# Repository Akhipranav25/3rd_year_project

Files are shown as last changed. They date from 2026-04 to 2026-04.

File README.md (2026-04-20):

# 3rd_year_project
Autonomous docking system for spacecraft
<br>
This repository contains all CAD and code files for the project.
<br>
<br>
The C++ code (arduino_robot_control_code_9.4.ino) is to be run on an Arduino microcontroller and the Python code (distance+pose+estimation+Arduino_v6.4.py) is intended to be run on a Raspberry Pi (recommended Raspberry Pi 4 Model B). The Arduino needs to be connected to the Raspberry Pi via USB for the programs to work. The Arduino program can work using inputs typed in the serial monitor on the Arduino IDE, but the Python program will not run if the Arduino is not connected. The Arduino does not have to have the corresponding program loaded, but there will likely be input buffer overflows if a different program (or no program) is used.
<br>
<br>
The STL files can be directly imported to a slicing software and 3D printed, while the STEP files can be imported into a 3D modelling software and edited. The PT-GD401.step file is the original scissor lift design from the source (GrabCAD [https://grabcad.com/library/stepper-motorized-labjack-pt-gd401-and-pt-gd402-1]) and can be edited or just used as a guide for how to connect the parts. Note that some parts, particularly the top and bottom covers are not critical and the design will function without them.

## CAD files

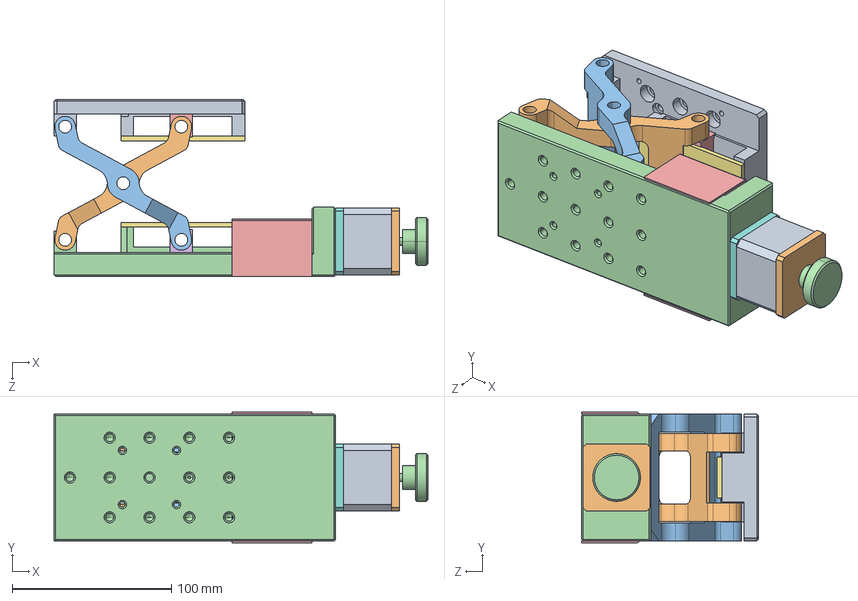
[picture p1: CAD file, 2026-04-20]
PT-GD401.STEP
235.0 x 82.0 x 111.1 mm
ZS10-60怢醱
囀盓殤
俋盓殤
ZS10-60菁啣
賑輸
螺母滑块
絳寢 x 2
YK42萇儂
护罩-60电动

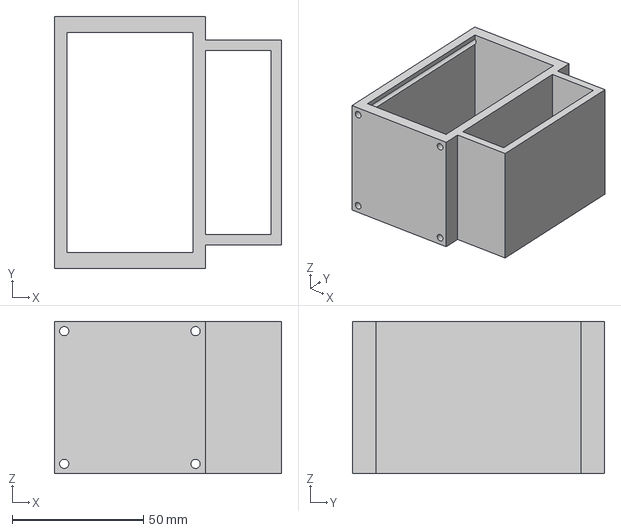
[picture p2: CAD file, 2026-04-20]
Powerbank_holder_v3.step
86.5 x 95.9 x 58.0 mm

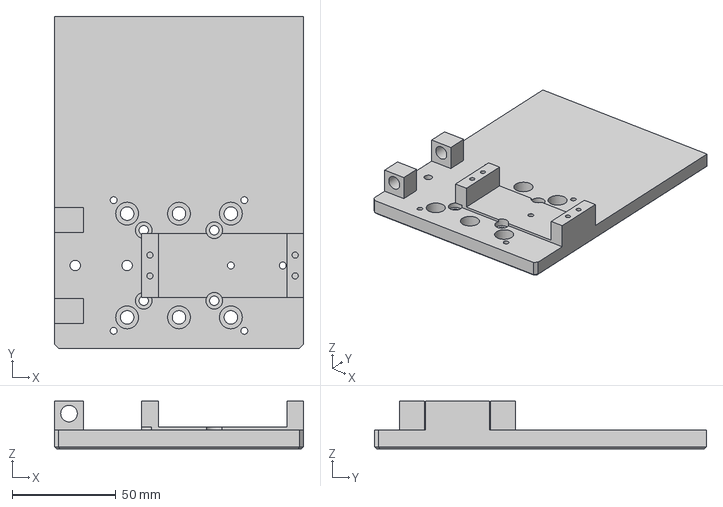
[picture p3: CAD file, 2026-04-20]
PT-GD401_top_updated_v1.step
120.0 x 160.0 x 23.0 mm

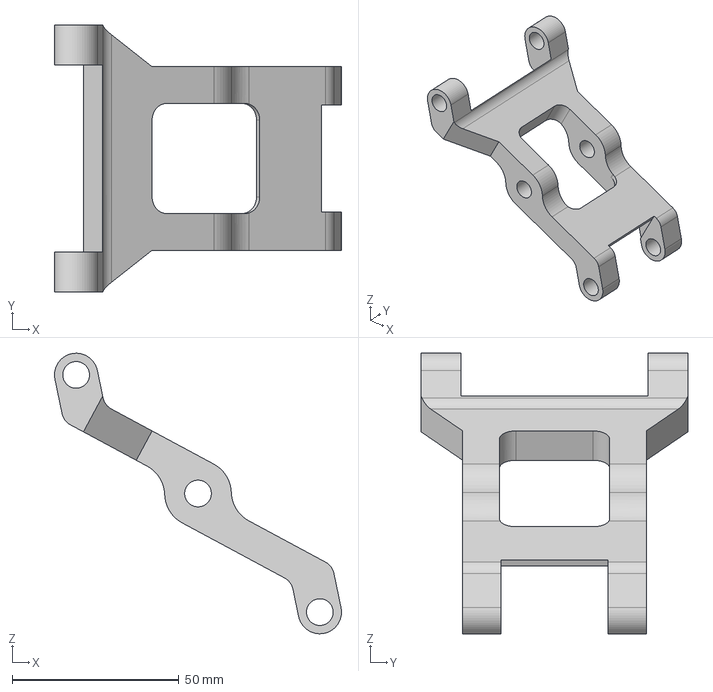
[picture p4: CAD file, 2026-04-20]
Lift_platform_1_arm_2.step
86.0 x 80.0 x 84.1 mm

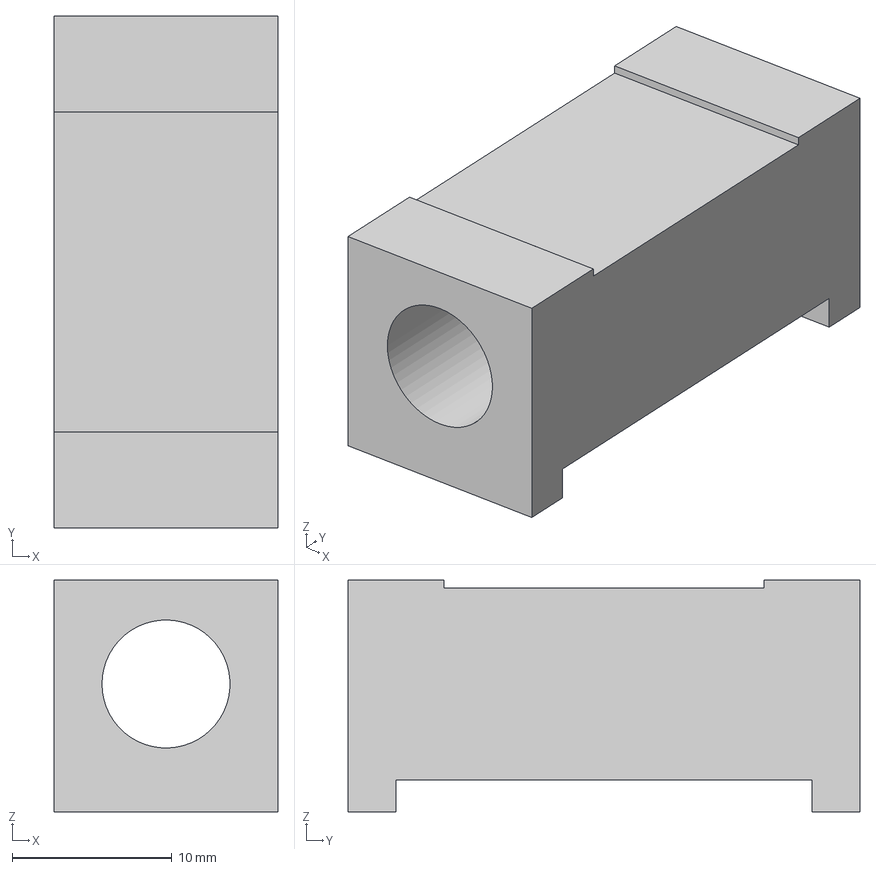
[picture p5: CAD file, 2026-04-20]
Lift_platform_1_top_slider.step
14.0 x 32.0 x 14.5 mm

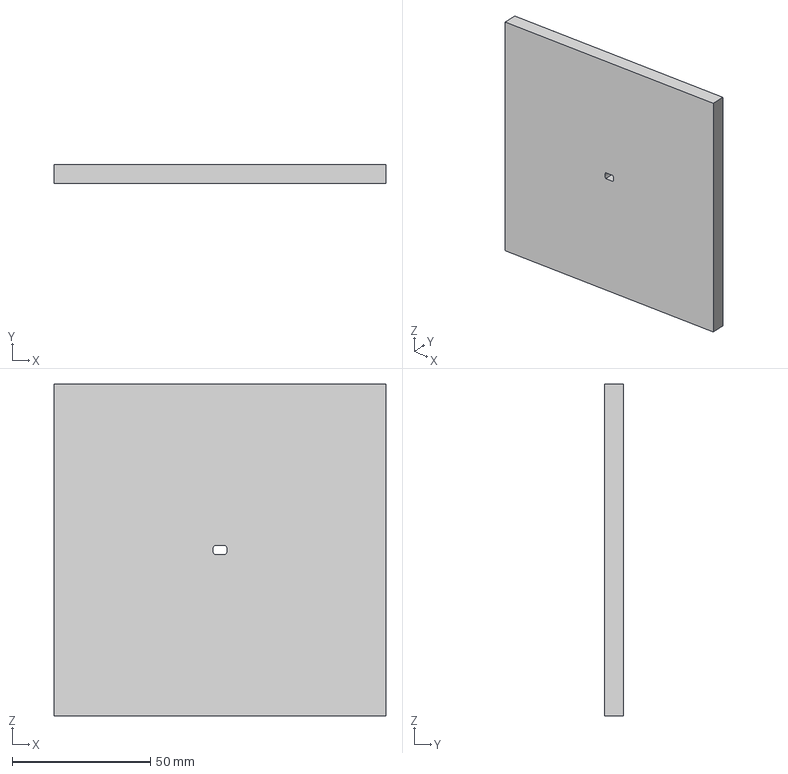
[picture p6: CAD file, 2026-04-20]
Stepper_motor_tag_mount_v1.step
120.0 x 7.00 x 120.0 mm

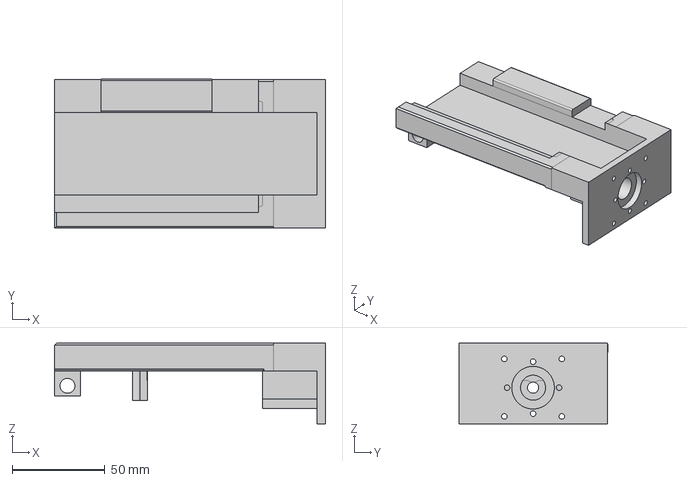
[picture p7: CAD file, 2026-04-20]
PT-GD401_updated_v2.6_motor_attachment_point.step
146.1 x 80.5 x 43.5 mm

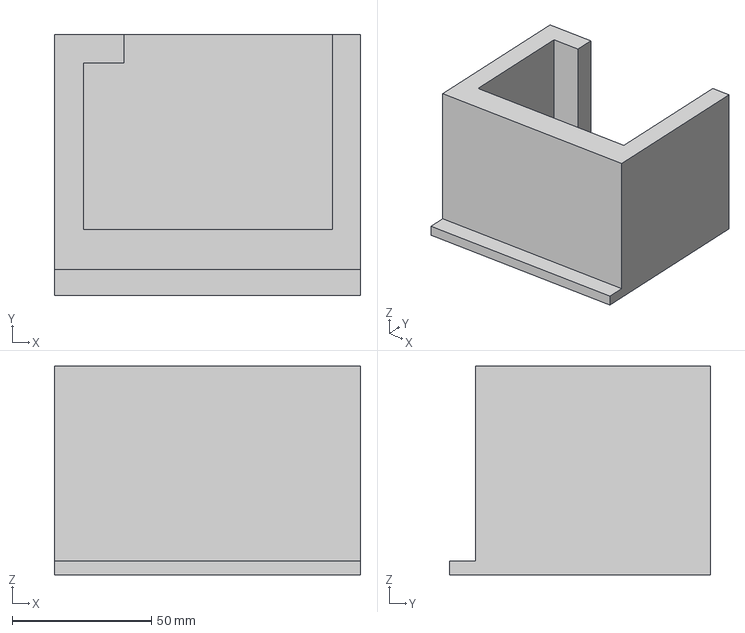
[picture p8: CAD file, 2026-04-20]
PT-GD401_updated_v2.6_extended_base.step
110.0 x 93.7 x 75.0 mm

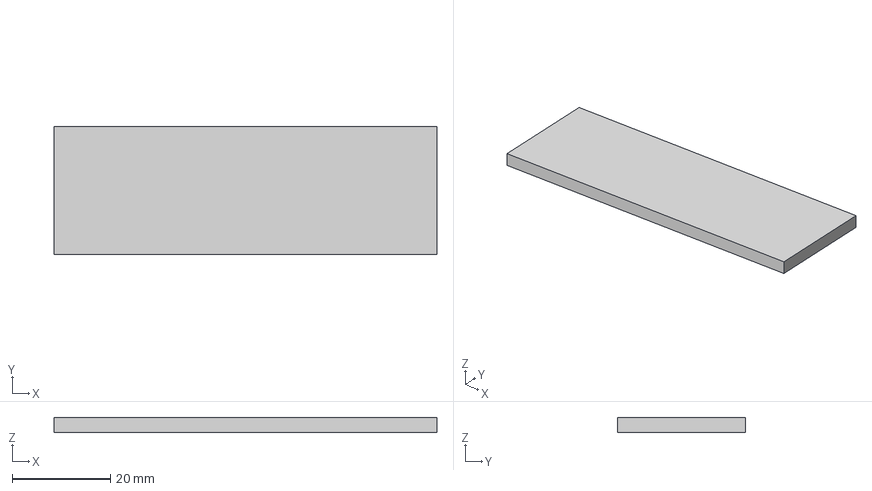
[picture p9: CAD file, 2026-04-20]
Lift_platform_1_bottom_cover.step
78.0 x 26.0 x 3.00 mm

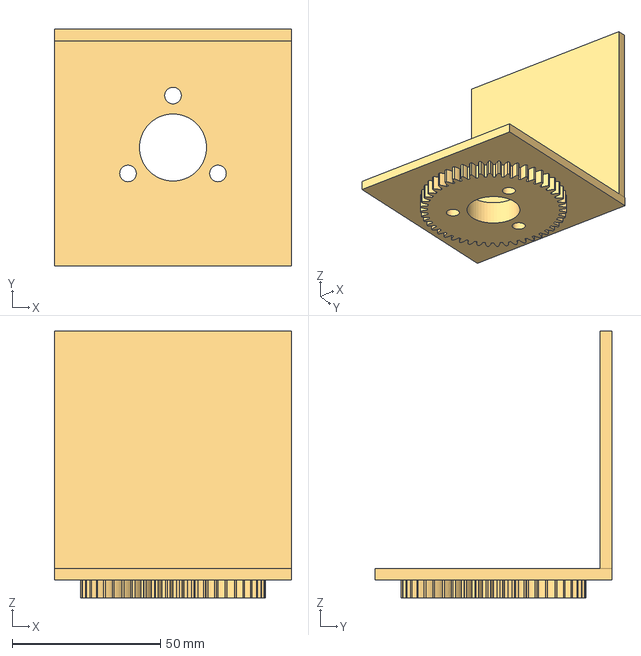
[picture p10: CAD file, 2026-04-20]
slip_ring_mount_v1.step
80.0 x 80.0 x 90.0 mm

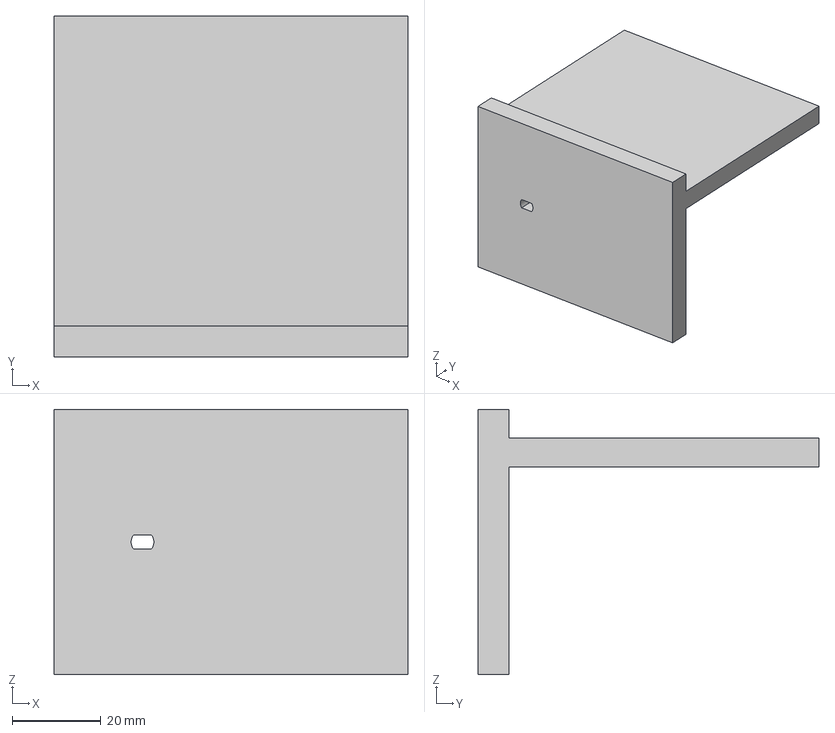
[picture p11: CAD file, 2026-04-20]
Stepper_motor_camera_mount_v1.step
80.0 x 77.0 x 60.0 mm

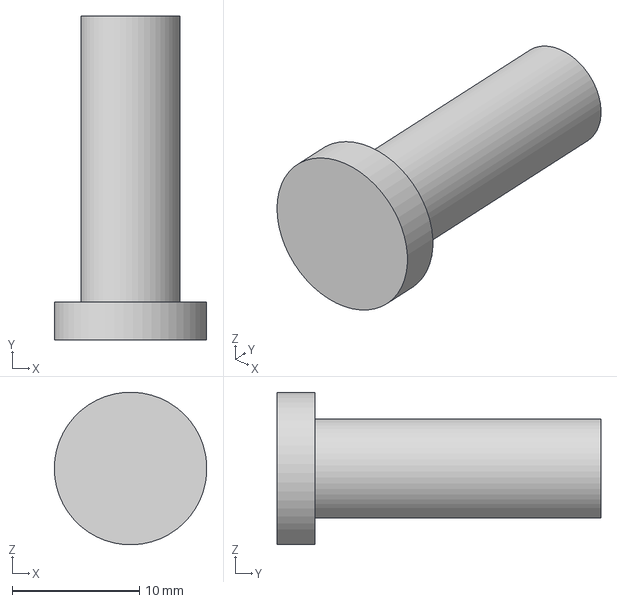
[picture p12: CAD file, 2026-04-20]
Scissor_lift_connector_v1.step
12.0 x 25.5 x 12.0 mm

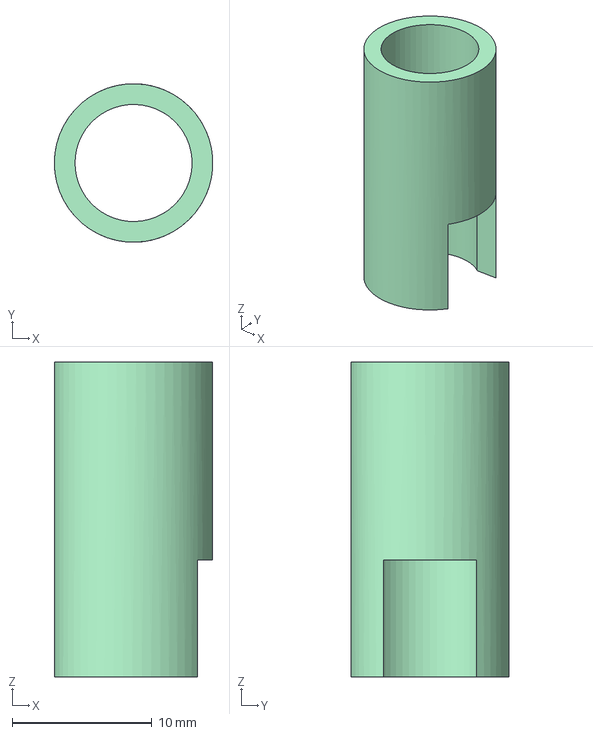
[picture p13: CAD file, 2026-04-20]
slip_ring_holder_v2.step
11.3 x 11.3 x 22.5 mm

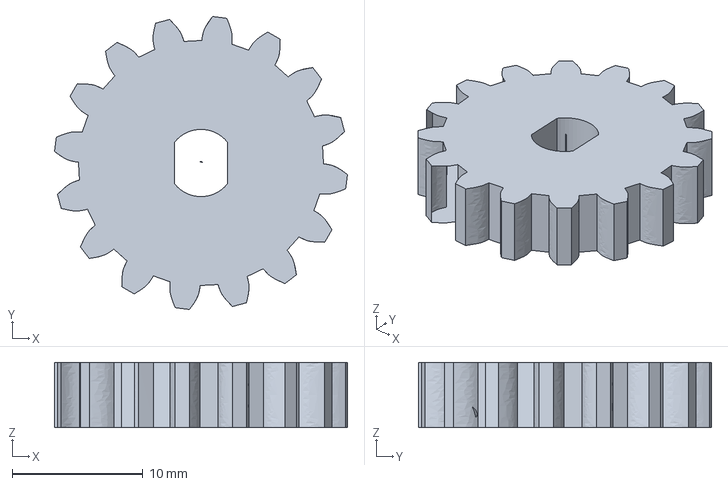
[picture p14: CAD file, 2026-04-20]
stepper_motor_gear_v1.step
22.4 x 22.4 x 5.00 mm

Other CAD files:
Lift_platform_1_top_cover.step
Lift_platform_1_bottom_slider.step
Lift_platform_1_arm_1.step
Lift_platform_1_bottom_housing.stl
DC_gear_motor_and_M6_bolt_head_coupler_v3.step
DC_gear_motor_and_M6_bolt_head_coupler_v3.stl
Lift_platform_1_arm_1.stl
Lift_platform_1_arm_2.stl
Lift_platform_1_base.stl
Lift_platform_1_bottom_cover.stl
Lift_platform_1_bottom_slider.stl
Lift_platform_1_top.stl
Lift_platform_1_top_cover.stl
Lift_platform_1_top_slider.stl
PT-GD401_top_updated_v1.stl
PT-GD401_updated_v2.6_extended_base.stl
PT-GD401_updated_v2.6_motor_attachment_point.stl
Powerbank_holder_v3.stl
Scissor_lift_connector_v1.stl
Stepper_motor_camera_mount_v1.stl
Stepper_motor_tag_mount_v1.stl
slip_ring_holder_v2.stl
slip_ring_mount_v1.stl
stepper_motor_gear_v1.stl

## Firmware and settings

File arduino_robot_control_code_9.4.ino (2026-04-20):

// Robot Control Code 9.3 - based on 9.1; clamps time interval for yaw integral to prevent excessive actuation and reverts to setting values less than 1 to 1 for translation because it took longer to adjust and not just when at 0 degrees to target, but at other angles as well, leading to significant time wastage
//changed yaw proportional gains from 2 to 4 and yaw derivative gains from 2 to 3
#define EN_PIN  A3
#define STEP_PIN A4
#define DIR_PIN  A5

int relay_pin1 = 24;
int relay_pin2 = 25;

int directionPinA = 12;
int pwmPinA       = 3;
int brakePinA     = 9;

int directionPinB = 13;
int pwmPinB       = 11;
int brakePinB     = 8;

float commandValue = 0;

float Kp_yaw = 4;
float Kd_yaw = 3; //originally 4, then 2, then 1, then 1.5, then 0, then
float Kd = 4000; //started with 2500 because assume sample time is 250ms (based on Python code command interval), so then -4*2500/250=40, which seemed like a good value to reduce control effort by.
float previous_left_commandval = 20;
long prev_l_Time;
float previous_right_commandval = 20;
long prev_r_Time;
float previous_yl_commandval = 90;
long prev_yl_Time;
float previous_yr_commandval = 90;
long prev_yr_Time;
float previous_f_commandval = 0;
long prev_f_Time;
float(TL_integral_sum) = 0;
float(TR_integral_sum) = 0;
float(YL_integral_sum) = 0;
float(YR_integral_sum) = 0;
float Forward_integral_sum = 0;
float Ki = 0.002; // originally 0.001, then 0.005, then 0.001, then 0.01, then 0.005, then 0.002
float Ki_yaw = 0.1; //originally 0.0005, then 0.001, then 0.01, then 0.1
float Ki_forward = 0.00001; // originally 0.0005, then 0.0001, then 0.00001

bool integral_enable = 0;

// ── Non-blocking stepper state ──────────────────────────────────────────────
// Previously moveSteps() used a blocking for-loop with delayMicroseconds().
// With noOfSteps=250 and microSecondsDelay=100 that was 250*2*100 = 50 ms of
// pure blocking per command — long enough to noticeably stall serial comms.
// Now the stepper is driven by micros() so loop() stays free.

int   stepDelay    = 200;          // µs between state transitions (half-period)
long  stepsRemaining = 0;          // >0 = forward, <0 = backward, 0 = idle
bool  stepPinState  = false;       // current STEP_PIN level
unsigned long lastStepMicros = 0;

long  step_counter = 0;            // absolute position tracking

// Call once per loop() to advance the stepper one half-step if due
void updateStepper() {
  if (stepsRemaining == 0) return;

  unsigned long now = micros();
  if (now - lastStepMicros < (unsigned long)stepDelay) return;

  lastStepMicros = now;

  stepPinState = !stepPinState;
  digitalWrite(STEP_PIN, stepPinState ? HIGH : LOW);

  // A full step = one LOW→HIGH transition
  if (stepPinState == HIGH) {
    if (stepsRemaining > 0) {
      stepsRemaining--;
      step_counter++;
    } else {
      stepsRemaining++;
      step_counter--;
    }
  }
}
// ────────────────────────────────────────────────────────────────────────────

int pwmValue = 0;

String data = "";

int percentage_array[10];
String instruction[10];
int command[6] = {-1,-1,-1,-1,-1,-1};
float commandval[6] = {-1.0,-1.0,-1.0,-1.0,-1.0,-1.0};
int percentage_count = 0;

int startSpace     = 0;
int startSeparator = 0;

void processData(String data) {
  int index = data.indexOf('%');

  while (index != -1) {
    percentage_array[percentage_count] = index;
    //Serial.print(percentage_array[percentage_count]);
    //Serial.print(" ");
    percentage_count++;
    index = data.indexOf('%', index + 1);
  }

  for (int p = 0; p < percentage_count; p++) {
    int endSpace   = percentage_array[p];
    instruction[p] = data.substring(startSpace, endSpace);
    //Serial.print(" | ");
    //Serial.print(instruction[p]);
    startSpace = endSpace + 1;
  }
  startSpace = 0;

  for (int m = 0; m < percentage_count; m++) {
    startSeparator = 0;
    int endSeparator = instruction[m].indexOf("?");
    if (endSeparator == -1) {
      command[m] = instruction[m].substring(startSeparator).toInt();
      commandval[m] = 0;
    } else {
      command[m] = instruction[m].substring(startSeparator, endSeparator).toInt();
      startSeparator = endSeparator+1;
      commandval[m] = instruction[m].substring(startSeparator).toFloat();
    }
    /*Serial.print(m);
    Serial.print(" ");
    Serial.print(command[m]);
    Serial.print(" ");
    Serial.print(commandval[m]);
    Serial.print(" | ");*/
  }
  
  startSeparator = 0;
  percentage_count = 0;
}

void setup() {
  Serial.begin(1000000);

  pinMode(directionPinA, OUTPUT);
  pinMode(pwmPinA,       OUTPUT);
  pinMode(brakePinA,     OUTPUT);

  pinMode(directionPinB, OUTPUT);
  pinMode(pwmPinB,       OUTPUT);
  pinMode(brakePinB,     OUTPUT);

  pinMode(EN_PIN,   OUTPUT);
  pinMode(STEP_PIN, OUTPUT);
  pinMode(DIR_PIN,  OUTPUT);
  pinMode(relay_pin1, OUTPUT);
  pinMode(relay_pin2, OUTPUT);

  prev_l_Time = millis();
  prev_r_Time = millis();
  prev_yl_Time = millis();
  prev_yr_Time = millis();
  prev_f_Time = millis();
}

void loop() {

  // ── Always service the stepper first, every loop iteration ────────────────
  updateStepper();
  // ──────────────────────────────────────────────────────────────────────────

  if (Serial.available() > 0) {

    while (Serial.available()) {
      char c = Serial.read();

      if (c == '<') {
        data = "";          // start of new message
      } else if (c == '>') {
        for (int command_iter = 0; command_iter < 6; command_iter++){
          command[command_iter] = -1;
          commandval[command_iter] = 0.0;
        }
        processData(data);  // full message received
      } else {
        data += c;
      }
    }

    for (int com_num = 0; com_num < (sizeof(command) / sizeof(command[0])); com_num++) {

      if (command[com_num] == 1) {
        // Translate left
        TR_integral_sum = 0;
        /*if (commandval[com_num] < 1){
          Ki = 0.4;
        }*/
        long current_l_Time = millis();
        pwmValue = constrain((commandval[com_num] * 1.1 + Kd*((commandval[com_num]-previous_left_commandval)/(current_l_Time-prev_l_Time)) + Ki*TL_integral_sum), 10, 255);
        digitalWrite(relay_pin2, LOW);
        //digitalWrite(brakePinA, HIGH);
        //analogWrite(pwmPinA, 0);
        digitalWrite(directionPinB, HIGH);
        digitalWrite(brakePinB, LOW);
        analogWrite(pwmPinB, pwmValue);
        if (integral_enable == 1){
          if (commandval[com_num] <= 1){
            commandval[com_num] = 1;
            TL_integral_sum = TL_integral_sum + commandval[com_num]*(current_l_Time-prev_l_Time);
          }
          TL_integral_sum = TL_integral_sum + commandval[com_num]*(250);
        }
        previous_left_commandval = commandval[com_num];
        prev_l_Time = current_l_Time;
        //Ki = 0.001;
      }
      else if (command[com_num] == 0) {
        // Translate right
        TL_integral_sum = 0;
        /*if (commandval[com_num] < 1){
          Ki = 0.4;
        }*/
        long current_r_Time = millis();
        pwmValue = constrain((commandval[com_num] * 2 + Kd*((commandval[com_num]-previous_right_commandval)/(current_r_Time-prev_r_Time)) + Ki*TR_integral_sum), 10, 255);
        digitalWrite(relay_pin2, LOW);
        //digitalWrite(brakePinA, HIGH);
        //analogWrite(pwmPinA, 0);
        digitalWrite(directionPinB, LOW);
        digitalWrite(brakePinB, LOW);
        analogWrite(pwmPinB, pwmValue);
        if (integral_enable == 1){
          if (commandval[com_num] <= 1){
            commandval[com_num] = 1;
            TR_integral_sum = TR_integral_sum + commandval[com_num]*(current_r_Time-prev_r_Time);
          }
          TR_integral_sum = TR_integral_sum + commandval[com_num]*(250);
        }
        previous_right_commandval = commandval[com_num];
        prev_r_Time = current_r_Time;
        //Ki = 0.001;
      }
      else if (command[com_num] == 2) {
        // ── FIX: queue steps instead of blocking ──────────────────────────
        // Was: moveSteps(noOfSteps)  — a 50 ms blocking for-loop.
        // Now: set direction once and add to stepsRemaining so updateStepper()
        //      fires them off asynchronously over many loop() iterations.
        if (step_counter <= 40000 && stepsRemaining == 0) {
          digitalWrite(DIR_PIN, LOW);
          stepsRemaining = 250;   // same as noOfSteps
        }
        // ──────────────────────────────────────────────────────────────────
      }
      else if (command[com_num] == 3) {
        // ── FIX: queue steps instead of blocking ──────────────────────────
        if (step_counter >= 0 && stepsRemaining == 0) {
          digitalWrite(DIR_PIN, HIGH);
          stepsRemaining = -250;  // negative = reverse direction
        }
        // ──────────────────────────────────────────────────────────────────
      }
      else if (command[com_num] == 4) {
        pwmValue = constrain((commandval[com_num] * 10), 40, 255);
        digitalWrite(brakePinB, HIGH);
        analogWrite(pwmPinB, 0);
        digitalWrite(directionPinA, LOW);
        digitalWrite(brakePinA, LOW);
        analogWrite(pwmPinA, pwmValue);
      }
      else if (command[com_num] == 5) {
        pwmValue = constrain((commandval[com_num] * 10), 40, 255);
        digitalWrite(brakePinB, HIGH);
        analogWrite(pwmPinB, 0);
        digitalWrite(directionPinA, HIGH);
        digitalWrite(brakePinA, LOW);
        analogWrite(pwmPinA, pwmValue);
      }
      else if (command[com_num] == 6) {
        // Yaw left
        YR_integral_sum = 0;
        long current_yl_Time = millis();
        pwmValue = constrain(commandval[com_num]*Kp_yaw + Kd_yaw*((commandval[com_num]-previous_yl_commandval)/(current_yl_Time-prev_yl_Time)) + Ki_yaw*YL_integral_sum, 10, 150); // + Ki*YL_integral_sum); constraint minimum was originally 60, and max was 255, then 200, then 150
        //digitalWrite(brakePinA, HIGH);
        //analogWrite(pwmPinA, 0);
        digitalWrite(relay_pin2, HIGH);
        digitalWrite(directionPinB, LOW);
        digitalWrite(brakePinB, LOW);
        analogWrite(pwmPinB, pwmValue);
        if (integral_enable == 1){
          if (commandval[com_num] <= 1){
            //commandval[com_num] = 1;
            if (current_yl_Time-prev_yl_Time > 500){
              YL_integral_sum = YL_integral_sum + commandval[com_num]*(500);
            }
            else{
              YL_integral_sum = YL_integral_sum + commandval[com_num]*(current_yl_Time-prev_yl_Time);
            }
          }
          YL_integral_sum = YL_integral_sum + commandval[com_num]*(250);
        }
        previous_yl_commandval = commandval[com_num];
        prev_yl_Time = current_yl_Time;
      }
      else if (command[com_num] == 7) {
        // Yaw right
        YL_integral_sum = 0;
        long current_yr_Time = millis();
        pwmValue = constrain(commandval[com_num]*Kp_yaw + Kd_yaw*((commandval[com_num]-previous_yr_commandval)/(current_yr_Time-prev_yr_Time)) + Ki_yaw*YR_integral_sum, 10, 150); // + Ki*YR_integral_sum; constraint minimum was originally 60, and max was 255, then 200, then 150
        //digitalWrite(brakePinA, HIGH);
        //analogWrite(pwmPinA, 0);
        digitalWrite(relay_pin2, HIGH);
        digitalWrite(directionPinB, HIGH);
        digitalWrite(brakePinB, LOW);
        analogWrite(pwmPinB, pwmValue);
        if (integral_enable == 1){
          if (commandval[com_num] <= 1){
            //commandval[com_num] = 1;
            if (current_yr_Time-prev_yr_Time > 500){
              YR_integral_sum = YR_integral_sum + commandval[com_num]*(500);
            }
            else{
              YR_integral_sum = YR_integral_sum + commandval[com_num]*(current_yr_Time-prev_yr_Time);
            }
          }
          YR_integral_sum = YR_integral_sum + commandval[com_num]*(250);
        }
        previous_yr_commandval = commandval[com_num];
        prev_yr_Time = current_yr_Time;
      }
      else if (command[com_num] == 10) {
        // Move forward
        //integral_enable = 0;
        long current_f_Time = millis();
        pwmValue = constrain((commandval[com_num]-20)*2 + Kd*((commandval[com_num]-previous_f_commandval)/(current_f_Time-prev_f_Time)) + Ki_forward*Forward_integral_sum, 40, 255);
        //digitalWrite(brakePinB, HIGH);
        //analogWrite(pwmPinB, 0);
        digitalWrite(directionPinA, HIGH);
        digitalWrite(brakePinA, LOW);
        analogWrite(pwmPinA, pwmValue);
        if (commandval[com_num] < 50){
          Forward_integral_sum = Forward_integral_sum + commandval[com_num]*(current_f_Time-prev_f_Time);
        }
        previous_f_commandval = commandval[com_num];
        prev_f_Time = current_f_Time;
      }
      else if (command[com_num] == 11) {
        // Stop
        digitalWrite(brakePinB, HIGH);
        analogWrite(pwmPinB, 0);
        digitalWrite(brakePinA, HIGH);
        analogWrite(pwmPinA, 0);
      }
      else if (command[com_num] == 12) {
        // Stop left/right motion
        digitalWrite(brakePinB, HIGH);
        analogWrite(pwmPinB, 0);
      }
      else if (command[com_num] == 13) {
        // Stop forward motion
        digitalWrite(brakePinA, HIGH);
        analogWrite(pwmPinA, 0);
        integral_enable = 1;
        //Kd = 0;
      }
      else if (command[com_num] == 14) {
        // Reset integral sums to zero
        integral_enable = 0;
        TL_integral_sum = 0;
        TR_integral_sum = 0;
        YL_integral_sum = 0;
        YR_integral_sum = 0;
        Forward_integral_sum = 0;
        previous_left_commandval = 100;
        prev_l_Time = millis();
        previous_right_commandval = 100;
        prev_r_Time = millis();
        previous_yl_commandval = 100;
        prev_yl_Time = millis();
        previous_yr_commandval = 100;
        prev_yr_Time = millis();
        previous_f_commandval = 500;
        prev_f_Time = millis();
        Kd = 4000;
      }
    }
  }
}

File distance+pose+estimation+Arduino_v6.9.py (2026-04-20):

#added 15 flag to show command 14 active

import cv2 as cv
from cv2 import aruco
import numpy as np
import math
import serial
import time
import RPi.GPIO as GPIO

command14_active = False
command11_start_time = None
command11_active = False
integral_reset_time = 20 #seconds

yaw_averaging_active = False
yaw_deg_list = []

ser = serial.Serial('/dev/ttyACM0', 1000000, timeout=1)
ser.reset_input_buffer()

calib_data_path = r"/home/akhipranav25/Documents/3rd_year_project/my_code/calibration_savez.npz"

calib_data = np.load(calib_data_path)
print(calib_data.files)
cam_mat = calib_data["mtx"]
dist_coef = calib_data["dist"]
r_vectors = calib_data["rvecs"]
t_vectors = calib_data["tvecs"]

command = ""

COMMAND_INTERVAL = 0.25  # seconds — reduced from 0.55 s now that the Arduino is non-blocking

last_command_time = 0.0

MARKER_SIZE = 9

# ── FIX 1: Create the detector ONCE, outside the loop ─────────────────────────
# Previously this was inside `while True`, causing a fresh allocation every frame.
marker_dict = cv.aruco.getPredefinedDictionary(cv.aruco.DICT_6X6_250)
param_markers = cv.aruco.DetectorParameters()
detector = cv.aruco.ArucoDetector(marker_dict, param_markers)
# ──────────────────────────────────────────────────────────────────────────────

# Pre-build the object_points array once — it never changes
half_size = MARKER_SIZE / 2
object_points = np.array([
    [-half_size,  half_size, 0],
    [ half_size,  half_size, 0],
    [ half_size, -half_size, 0],
    [-half_size, -half_size, 0]
], dtype=np.float32)

cap = cv.VideoCapture(0)

while True:
    ret, frame = cap.read()
    if not ret:
        break

    gray_frame = cv.cvtColor(frame, cv.COLOR_BGR2GRAY)

    # ── FIX 2: Use the pre-built detector rather than reinstantiating it ───────
    marker_corners, marker_IDs, reject = detector.detectMarkers(gray_frame)
    # ──────────────────────────────────────────────────────────────────────────

    previous_command = command

    if marker_IDs is not None:
        cv.aruco.drawDetectedMarkers(frame, marker_corners, marker_IDs)

        if marker_corners:
            total_markers = range(0, marker_IDs.size)
            for ids, corners, i in zip(marker_IDs, marker_corners, total_markers):
                cv.polylines(
                    frame, [corners.astype(np.int32)], True, (0, 255, 255), 4, cv.LINE_AA
                )

                image_points = corners.reshape(4, 2)
                corners_int = image_points.astype(int)
                top_right   = corners_int[0].ravel()
                top_left    = corners_int[1].ravel()
                bottom_right = corners_int[2].ravel()
                bottom_left  = corners_int[3].ravel()

                success, rVec, tVec = cv.solvePnP(
                    object_points, image_points, cam_mat, dist_coef
                )

                distance = np.sqrt(
                    tVec[2][0] ** 2 + tVec[0][0] ** 2 + tVec[1][0] ** 2
                )

                R, _ = cv.Rodrigues(rVec)

                roll  = math.atan2(R[1, 0], R[0, 0])
                yaw   = math.atan2(-R[2, 0], math.sqrt(R[2, 1]**2 + R[2, 2]**2))
                pitch = math.atan2(R[2, 1], R[2, 2])

                yaw_deg   = math.degrees(yaw)
                pitch_deg = math.degrees(pitch)
                roll_deg  = math.degrees(roll)
                
                if tVec[0][0] >= 0:
                    tVec_distance_combo = 575*(tVec[0][0]**2)/(distance**2)
                elif tVec[0][0] <0:
                    tVec_distance_combo = -575*(tVec[0][0]**2)/(distance**2)

                cv.drawFrameAxes(frame, cam_mat, dist_coef, rVec, tVec, 4, 4)
                cv.putText(
                    frame,
                    f"id: {ids[0]} Dist: {round(distance, 2)}",
                    top_right,
                    cv.FONT_HERSHEY_PLAIN, 1.3, (0, 0, 255), 2, cv.LINE_AA,
                )
                cv.putText(
                    frame,
                    f"x:{round(tVec[0][0],1)} y: {round(tVec[1][0],1)} ",
                    bottom_left,
                    cv.FONT_HERSHEY_PLAIN, 1.0, (0, 0, 255), 2, cv.LINE_AA,
                )
                angle_text = f"pitch:{round(pitch_deg, 2)} \nyaw:{round(yaw_deg, 2)} \nroll:{round(roll_deg, 2)}"
                y0, dy = 0, 20
                for line_i, line in enumerate(angle_text.split('\n')):
                    y = y0 + line_i * dy
                    cv.putText(
                        frame,
                        line,
                        bottom_right + (0, y),
                        cv.FONT_HERSHEY_PLAIN, 1.0, (0, 0, 255), 2, cv.LINE_AA,
                    )

            # Build command string from the last-processed marker's tVec / angles
            command = ""
            if round(tVec[1][0], 1) > 0.1: #threshold changed from 0.05 and added rounding to reduce sensitivity
                command += "3%"
            elif round(tVec[1][0], 1) < -0.1: #threshold changed from -0.05 and added rounding to reduce sensitivity
                command += "2%"

            if tVec_distance_combo > 0.05 and yaw_deg > 4:
                command += "7?" + str(round(yaw_deg)) + "%"

            elif tVec_distance_combo < -0.05 and yaw_deg < -4:
                command += "6?" + str(round(-yaw_deg)) + "%"
            
            elif tVec_distance_combo > 0.05:
                command += "0?" + str(round(tVec_distance_combo, 2)) + "%"
            elif tVec_distance_combo < -0.05:
                command += "1?" + str(abs(round(tVec_distance_combo, 2))) + "%"

            if yaw_deg > 4 and yaw_deg <= 180 and tVec_distance_combo <= 0.05 and tVec_distance_combo >= -0.05:
                command += "7?" + str(round(yaw_deg)) + "%"
            elif yaw_deg < -4 and yaw_deg > -180 and tVec_distance_combo <= 0.05 and tVec_distance_combo >= -0.05:
                command += "6?" + str(round(-yaw_deg)) + "%"
                
            elif tVec_distance_combo <= 0.05 and tVec_distance_combo >= -0.05 and not yaw_averaging_active and not command11_active:
                command += "12%"
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

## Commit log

2026-04-10 Add files via upload
    Added STL files for CAD and latest Python and Arduino files
    [DC_gear_motor_and_M6_bolt_head_coupler_v3.stl, PT-GD401_top_updated_v1.stl, PT-GD401_updated_v2.6_extended_base.stl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]
2026-04-20 STEP files added
    [DC_gear_motor_and_M6_bolt_head_coupler_v3.step]
2026-04-20 Fix typo in Arduino description in README.md
2026-04-20 Update README with Arduino and Python code details
    Added details about the Arduino and Python code requirements, including connection notes and usage instructions.
